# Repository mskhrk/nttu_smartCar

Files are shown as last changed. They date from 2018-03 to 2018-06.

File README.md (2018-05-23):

# nttu_smartCar(Accident detection-home-robot)
居家意外偵測智慧機器人車(Accident detection-home-robot)

歡迎來到國立台東大學資訊工程系的此開源專案

我們志在建立一個自動化的機器裝置，以解決居家意外發生時的問題

我們使用Arduino+linux實現了一個可在家中自動巡邏的機器人車

目前實作完成的項目有機器人車控制(硬體部分)、地圖路徑規劃

目前正在進行中的項目有機器人車控制(軟體部分)、地圖路徑繪製、opencv影像辨識

機器人車控制使用程式語言為 C 

使用 opencv 版本2.4.9 

運作環境 ubuntu-12.04.5 on zedboard zynq-7000

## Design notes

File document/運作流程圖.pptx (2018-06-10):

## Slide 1

main主體

共用全域變數

共用資料結構

智能車主控制程式
(初始狀態設定)
(執行緒建立)

意外檢測
(pthread1)

意外檢測功能
accident_decection.c

accident_decection()

車子相關Io控制
(pthread2)

carMove()

車子相關Io控制功能
carMove.c

影像辨識
(pthread3)

影像辨識功能
image_recognition.c

image_recognition()

無線網路IO&判斷(pthread4)

黃色底色
(待驗證)

treatWifi()

無線網路資料接收
treatWifi.c

紅色底色
(未開始)

橘色底色
(進行中)

綠色底色
(已完成)

## uart_send_command()函數說明

- 在此說明中以uart_send_command() 已usc()表示
- 需與Arduino library(car_all_v5.1.ino)結合使用， usc()用於透過uart傳送指令給Arduino，並且接收Arduino回傳回來的資料，並存於特定檔案(預設data1.txt)之中。
- 目前有uart_send_command()和uart_send_command2()兩個版本，兩者差異在於傳入的參數不同， uart_send_command2() 可自行設定要寫入的檔案名與寫入模式。
- data1.txt為接收資料的暫存檔需搭配使用fixfile()和load_data()才可取出數值使用
- 如果只是要傳送指令而不需接收回傳資料，建議直接使用system()功能。

## fixfile()、 load_data() 函數說明

- fixfile() 是 uart_send_command() 功能的後續處理函式，目的在於將uart_send_command() 所寫入的檔案(data1.txt)進行雜訊處理與資料筆數計算， data1.txt處理後會以data2.txt儲存。
- load_data() 是 fixfile() 功能的後續處理函式，目的在於將data2.txt的資料載入到記憶體中。
- uart_send_command()、 fixfile() 、 load_data() 為相依的程式功能，目的在於將Arduino 送出的特定格式資料進行儲存(disk)與載入(memory)使用。

## 地圖路徑規劃

- 可依照現有地圖(外部環境資訊)，計算出一條可以從起點移動至目標點的路徑。
- 藉由路徑規劃可以實現在有地圖的狀態下，可在空間中進行避障移動。

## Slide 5

實際規劃結果

實際地圖檔案

y

#23 -5003-5002-999-17-0-22-0-0-0-

#22 -5003-5001-999-23-0-21-0-0-0-

#21 -5003-5000-999-22-0-0-20-0-0-

#20 -5002-5000-999-0-21-0-8-0-0-

#19 -5005-5003-999-0-0-0-18-0-0-

#18 -5004-5003-999-0-19-0-17-0-0-

#17 -5003-5003-999-0-18-23-15-0-0-

#16 -5002-5004-999-0-0-15-12-0-0-

#15 -5002-5003-999-16-17-0-11-0-0-

#14 -5001-5006-999-0-0-13-7-0-0-

#13 -5001-5005-999-14-0-12-6-0-0-

#12 -5001-5004-999-13-16-11-5-0-0-

#11 -5001-5003-999-12-15-10-4-0-0-

#10 -5001-5002-999-11-0-9-3-0-0-

#9 -5001-5001-999-10-0-8-2-0-0-

#8 -5001-5000-999-9-20-0-1-0-0-

#7 -5000-5006-999-0-14-6-0-0-0-

#6 -5000-5005-999-7-13-5-0-0-0-

#5 -5000-5004-999-6-12-4-0-0-0-

#4 -5000-5003-999-5-11-3-0-0-0-

#3 -5000-5002-999-4-10-2-0-0-0-

#2 -5000-5001-999-3-9-1-0-0-0-

#1 -5000-5000-999-2-8-0-0-0-0-

7

14

5006

5005

6

13

5004

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
5003

3

10

23

5002

5001

2

9

22

5000

1

5000

8

5001

20

21

X

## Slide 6

實際規劃結果

實際地圖檔案

y

#23 -5003-5002-999-17-0-22-0-0-0-

#22 -5003-5001-999-23-0-21-0-0-0-

#21 -5003-5000-999-22-0-0-20-0-0-

#20 -5002-5000-999-0-21-0-8-0-0-

#19 -5005-5003-999-0-0-0-18-0-0-

#18 -5004-5003-999-0-19-0-17-0-0-

#17 -5003-5003-999-0-18-23-15-0-0-

#16 -5002-5004-999-0-0-15-0-0-0-

#15 -5002-5003-999-16-17-0-0-0-0-

#14 -5001-5006-999-0-0-13-7-0-0-

#13 -5001-5005-999-14-0-0-6-0-0-

#12 -5001-5004-999-0-0-0-0-0-0-

#11 -5001-5003-999-0-0-0-0-0-0-

#10 -5001-5002-999-0-0-9-3-0-0-

#9 -5001-5001-999-10-0-8-2-0-0-

#8 -5001-5000-999-9-20-0-1-0-0-

#7 -5000-5006-999-0-14-6-0-0-0-

#6 -5000-5005-999-7-13-5-0-0-0-

#5 -5000-5004-999-6-0-4-0-0-0-

#4 -5000-5003-999-5-0-3-0-0-0-

#3 -5000-5002-999-4-10-2-0-0-0-

#2 -5000-5001-999-3-9-1-0-0-0-

#1 -5000-5000-999-2-8-0-0-0-0-

7

14

5006

5005

6

13

5004

5

16

4

15

17

18

19

5003

3

10

23

5002

5001

2

9

22

5000

1

5000

8

5001

20

21

X

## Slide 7

實際規劃結果

實際地圖檔案

y

#23 -5003-5002-999-0-0-22-0-0-0-

#22 -5003-5001-999-23-0-21-0-0-0-

#21 -5003-5000-999-22-0-0-20-0-0-

#20 -5002-5000-999-0-21-0-8-0-0-

#19 -5005-5003-999-0-0-0-18-0-0-

#18 -5004-5003-999-0-19-0-0-0-0-

#17 -5003-5003-999-0-0-0-0-0-0-

#16 -5002-5004-999-0-0-15-12-0-0-

#15 -5002-5003-999-16-0-0-0-0-0-

#14 -5001-5006-999-0-0-13-7-0-0-

#13 -5001-5005-999-14-0-12-6-0-0-

#12 -5001-5004-999-13-16-0-5-0-0-

#11 -5001-5003-999-0-0-0-0-0-0-

#10 -5001-5002-999-0-0-9-3-0-0-

#9 -5001-5001-999-10-0-8-2-0-0-

#8 -5001-5000-999-9-20-0-1-0-0-

#7 -5000-5006-999-0-14-6-0-0-0-

#6 -5000-5005-999-7-13-5-0-0-0-

#5 -5000-5004-999-6-12-4-0-0-0-

#4 -5000-5003-999-5-0-3-0-0-0-

#3 -5000-5002-999-4-10-2-0-0-0-

#2 -5000-5001-999-3-9-1-0-0-0-

#1 -5000-5000-999-2-8-0-0-0-0-

7

14

5006

5005

6

13

5004

5

12

16

4

15

18

19

5003

3

10

23

5002

5001

2

9

22

5000

1

5000

8

5001

20

21

X

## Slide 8

實際規劃結果

實際地圖檔案

y

#23 -5003-5002-999-17-0-22-0-0-0-

#22 -5003-5001-999-23-0-21-0-0-0-

#21 -5003-5000-999-22-0-0-20-0-0-

#20 -5002-5000-999-0-21-0-8-0-0-

#19 -5005-5003-999-0-0-0-18-0-0-

#18 -5004-5003-999-0-19-0-17-0-0-

#17 -5003-5003-999-0-18-23-15-0-0-

#16 -5002-5004-999-0-0-15-12-0-0-

#15 -5002-5003-999-16-17-0-11-0-0-

#14 -5001-5006-999-0-0-13-7-0-0-

#13 -5001-5005-999-14-0-12-6-0-0-

#12 -5001-5004-999-13-16-11-5-0-0-

#11 -5001-5003-999-12-15-10-4-0-0-

#10 -5001-5002-999-11-0-0-3-0-0-

#9 -5001-5001-999-0-0-0-0-0-0-

#8 -5001-5000-999-0-20-0-1-0-0-

#7 -5000-5006-999-0-14-6-0-0-0-

#6 -5000-5005-999-7-13-5-0-0-0-

#5 -5000-5004-999-6-12-4-0-0-0-

#4 -5000-5003-999-5-11-3-0-0-0-

#3 -5000-5002-999-4-10-0-0-0-0-

#2 -5000-5001-999--0-0-0-0-0-

#1 -5000-5000-999-0-8-0-0-0-0-

7

14

5006

5005

6

13

5004

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
5003

3

10

23

5002

5001

22

5000

1

5000

8

5001

20

21

X

## 外部環境偵測與地圖建立

- 1.使用超聲波感測器對外部環境進行掃描。
- 2.zedboard發出控制arduino指令:要求回傳超聲波感測器取得數值。
- 3.arduino 接收指令控制步進馬達轉動與超聲波感測器進行資料收集，並回傳zedboard感測器取得的數值。
- 4.zedboard對數值進行處理並依造格式轉換為地圖檔。

## 外部環境偵測與地圖建立

- 藉由超聲波感測器回傳的數值計算牆壁距離並生成地圖

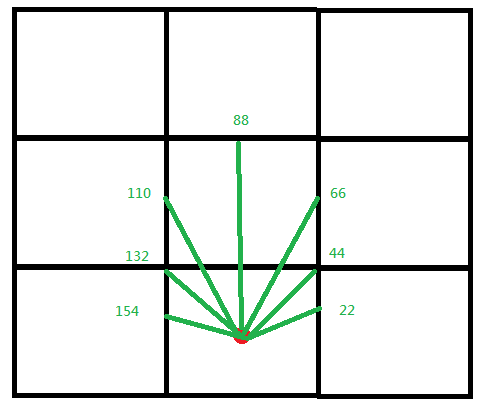
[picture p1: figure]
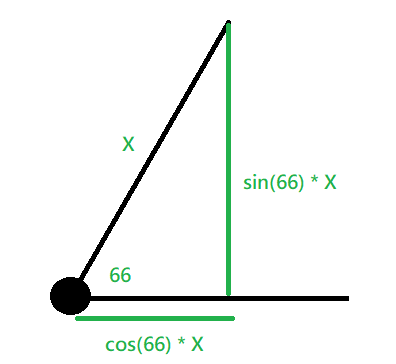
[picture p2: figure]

## 地圖說明

- 用途:用於紀錄車子曾經走過的路徑、移動方式、外部環境樣貌，並結合路徑規劃，使車子可在空間中移動、避障。
- 地圖格式:為了可以方便做資料存取，定義出的一個格式
使用 “#” 作為開頭 “-” 與空白作為分隔，資料以數字表示。
#數字空白-數字-數字-數字-數字-數字-數字-數字-數字-數字-

在此儲存格式下每個位置的資料將有不同的資料含意。

## 地圖說明-資料意義(格式999)

- #序號 -X-Y-格式999-北-東-南-西-分區-預留-(環境資訊)
序號:用於從地圖檔讀取資料的key，儲存序號由1開始向後累加，當同一份地圖檔當中出現重複序號時以最新一筆為讀取目標。
序號0:為定義地圖檔案的標頭與結尾，不儲存資料。
- X Y:分別儲存地圖中x軸y軸的位置。
- 格式:利用數字定義後面儲存的資料格式，使地圖檔可以存放各種不同意義的資料。
  - 格式999說明(記錄環境資訊) :
#序號空格-X-Y-格式999-北-東-南-西-分區-預留
#1 -5000-5000-999-2-8-0-0-0-0-
此例中代表在序號1這一個位置中 向北是序號2，東為序號8，0則代表無路可走，也就是代表0是邊界或障礙。

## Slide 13

主架構

細部流程

多選多
流程1

多選多
流程2

多選一流程1

多選一流程2

紅色底色
(未開始)

橘色底色
(進行中)

黃色底色
(待驗證)

綠色底色
(已完成)

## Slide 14

車子啟動

回傳
地圖可用訊號
將目前位置與方位寫入全域變數

檢測目前
位置與方位

目的讓車子獲得起始資訊
以利後續功能運作

校正(設定)
車子移動參數

控制車子對自身狀態檢測

人工把車子狀態設定

目的讓車子之後的移動可以精準
以利操作

依方位與
地圖ID移動

等待移動指令

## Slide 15

校正(設定)
車子移動參數

自動校正

手動輸入

完成校正

使用linux timer
計時

面向牆壁

結束移動訊號

修改移動參數

紀錄目前距離

開始移動訊號

計時器停止

比較之前距離
計算移動時間

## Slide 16

檢測目前
位置與方位

建立
初始環境

檢測地圖可用性

建立新地圖

判斷失敗

回傳地圖ID
和面相方位

判斷成功

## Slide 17

建立
初始環境

使用modeJ
環境掃描
(開機時北方)

使用initScanXY()
把初始環境
資料存於
car.map

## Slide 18

檢測地圖可用性

檢測目前車子位於地圖中哪一個點

回傳失敗

判斷失敗

回傳目前
位置ID
和面相方位

判斷成功

和現有地圖每1筆比對

相機qrcode 判斷

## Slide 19

建立新地圖

發送探測指令

接收回傳
資料

資料修正與轉換

回傳最終點地圖ID
和面相方位

將資料加上ID
寫入地圖檔

不是最終點

是最終點

依演算法
移動到下一個點

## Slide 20

依演算法
移動到下一個點

判斷地圖還是否
需要繼續製作

距離與XY轉換
車子面向方向
地圖資料更新

一般行走規則

1直走
2最遠45度角
3右優先

移動規則

前4步行走規則

1找四邊緣
2找四邊角

依規則、現有資料判斷
計算下一步命令

送出移動方向和距離

實際移動功能

遇到邊界點

1退回上一個點
2並記錄此點

地圖邊界擴張與結束

計算是否有超出初始邊界的點
如有從此點再做前4步行走直到無邊界外的點

## 程式

car_all_v5.0.ino arduino原始碼
uart_setting.c uart設定函式
sm_car.c 智能車操作函式庫
https://drive.google.com/drive/folders/0BysmffTc7ivUeC1XWUVXUlh1bUE?usp=sharing
-----------------------------------測試code--------------------------------------------
timerInThread.c linux計時器與執行緒測試
timerInThreadJ 定時超音波避障測試

## 預估問題

- 可能問題車子實際移動不符合預期
- 移動角度不准、誤差累積
- 移動時的控制流程(和其他執行緒的相依關係)
- http://viml.nchc.org.tw/blog/paper_info.php?CLASS_ID=1&SUB_ID=1&PAPER_ID=435

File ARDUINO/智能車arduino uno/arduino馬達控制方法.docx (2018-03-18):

頻道A

指令 指令說明 參數 參數說明

1 向前移動 1~9 向前移動1格上限為9格1格定義為60cm

2 向後移動 1~9 向後移動1格上限為9格1格定義為60cm

頻道B

指令 指令說明 參數1 參數1說明 參數2 參數2說明

1 向右移動 1~9 移動時間(秒) 1~3 表示旋轉程度

2 向左移動 1~9 移動時間(秒) 1~3 表示旋轉程度

旋轉程度細節說明 :

程度1 急轉:轉90度後直走此時參數1為轉完後直走時間

程度2 快速側轉此時參數1為側轉全程時間

程度3 側偏此時參數1為側偏全程時間

頻道C

指令 指令說明

0 停止

1 前進

2 後退

頻道D

指令 指令說明 參數 參數說明

1 向右 0~4 轉彎模式

2 向左 0~4 轉彎模式

旋轉模式細節說明 :

0迴旋

1慢速向前

2慢速向後

3快速向前

4快速向後

頻道E

指令 指令說明 參數 參數說明

1 控制速度 1~3 1:高速 2:中速 3:低速

2 控制速度 空1~255 分號 需空一格 1:最低速 255:最高速 (和F5一樣)

3 控制速度 1~2 1:+10單位 2:-10單位 max:255 min:70

4 掃描開關 0~1 0關 1開

頻道F

指令 指令說明 參數 參數說明

1 格子距離 空 1~ 分號 需空一格 走60cm的時間 預設990(ns)

2 誤差距離 空 1~ 分號 需空一格 前進時煞車距離誤差 預設50(ns)

3 誤差距離 空 1~ 分號 需空一格 轉90度的時間 預設900(ns)

4 誤差距離 空 1~ 分號 需空一格 轉180度的時間 預設1900(ns)

5 控制速度 空 1~255分號 需空一格 1:最低速 255:最高速 預設200(ns)

頻道G

指令 指令說明

1 一邊自轉一邊送超音波探測

參數1 參數1說明

空 1~255 旋轉速度(車子轉的速度)

參數2 參數2說明

空 1~ 旋轉時間(車子轉一圈的總時間)

參數3 參數3說明

空 1~ 分號 超音波可測最遠time out(3000時約等於50cm)

頻道H

指令 指令說明

1 可個別控制4個輪子

參數1 參數1說明

空 0~255 or 空1001~1255 rf旋轉速度(車子轉的速度)正轉255 反轉1255 參數2 參數2說明

空 0~255 or 空1001~1255 lb旋轉速度(車子轉的速度)正轉255反轉1255

參數3 參數3說明

空 0~255 or 空1001~1255 rb旋轉速度(車子轉的速度)正轉255 反轉1255

參數4 參數4說明

空 0~255 or 空1001~1255 分號 lf旋轉速度(車子轉的速度)正轉255 反轉1255

頻道I

開始掃描/停止掃描

頻道J

指令 指令說明

1 依照參數回傳旋轉角度超音波讀取值

參數1 參數1說明

空 0~180 起始角度
參數2 參數2說明

空 0~180 結束角度

參數3 參數3說明

空 0~180 每一次轉動的角度

參數4 參數4說明

空 0~20 每一次轉動的超音波發射次數

參數5 參數5說明

空 0~ 分號 每一次轉動的timeout(3000時約等於50cm)

指令 指令說明

2 依照參數回傳單一指定方向超音波讀取值並當回傳值小於20時stopFlag=1

參數1 參數1說明

空 0~180 旋轉角度

參數2 參數2說明

空 0~20 每一次轉動的超音波發射次數

參數3 參數3說明

空 0~ 分號 每一次轉動的timeout(3000時約等於50cm)

頻道K

指令 指令說明 參數 參數說明

1 右旋轉 空1~ 360分號 須為15的倍數

2 左旋轉 空1~ 360分號 須為15的倍數

頻道P

印出目前全域變數

範例

向前走3格:A13

右轉90度後直走2秒:B21

速度改用中速:E12

速度改用自訂義:E2 200;

轉速50 轉4000 ms timeout 3000us G1 50 4000 3000;

印出目前全域變數 P

echo "D10" > /dev/ttyPS1

echo "H1 200 200 200 200;" > /dev/ttyPS1

echo "C1" > /dev/ttyPS1

echo "E2 255;" > /dev/ttyPS1

echo "J1 20 160 5 3;" > /dev/ttyPS1

echo "F6 170;" > /dev/ttyPS1

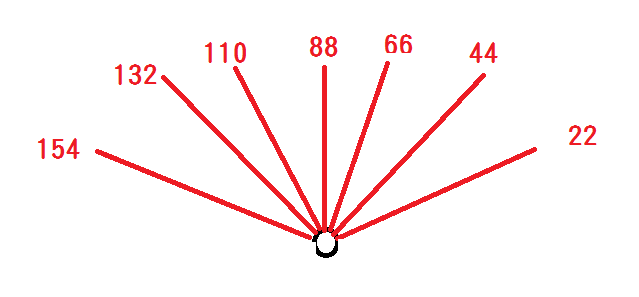
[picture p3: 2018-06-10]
document/picture/seven directional scanning.png

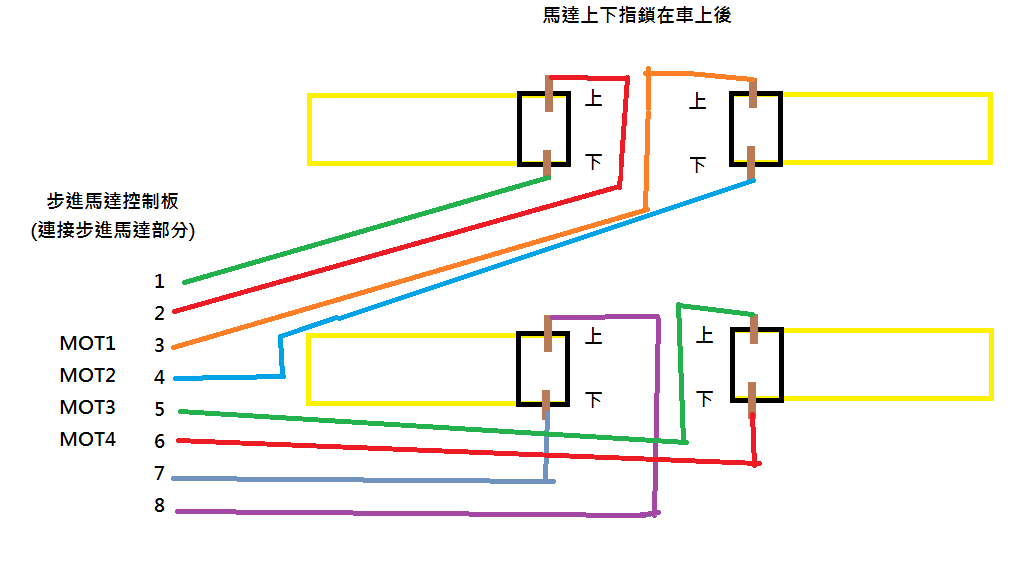
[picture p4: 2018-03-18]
document/智能車電路接線3.png

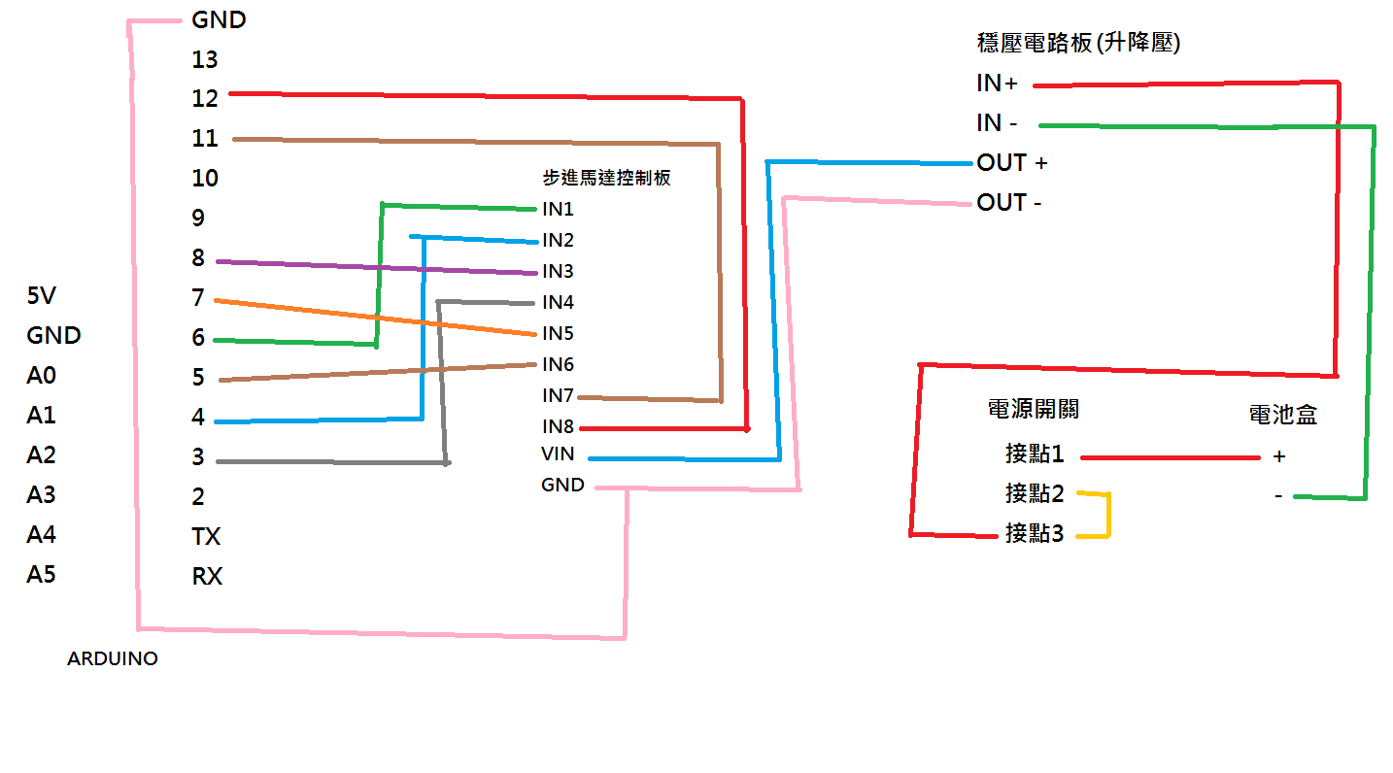
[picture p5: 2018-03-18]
document/智能車電路接線2.png

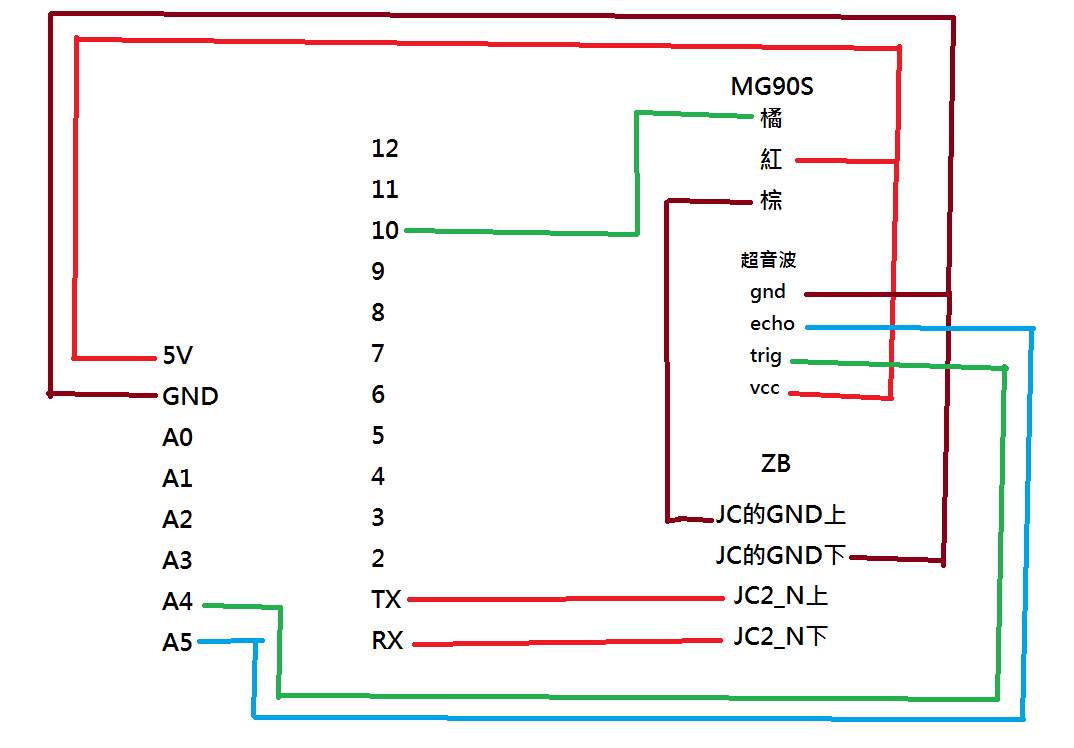
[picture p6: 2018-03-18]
document/智能車電路接線.png

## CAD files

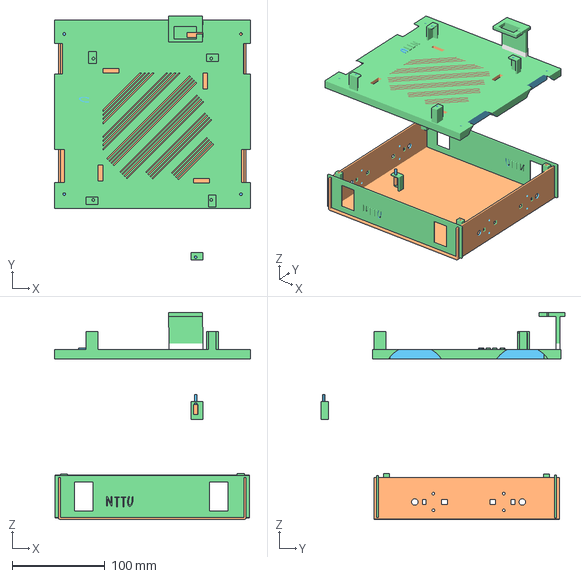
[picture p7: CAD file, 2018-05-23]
3D/car3D.3mf
211.9 x 263.3 x 223.5 mm

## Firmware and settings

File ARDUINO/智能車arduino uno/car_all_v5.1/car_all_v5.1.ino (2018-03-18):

#include <MsTimer2.h>
#include <Servo.h>
/*馬達*/
Servo myservo;

/*移動參數*/
int OneFloorDelay = 890;    //一片木地板行走時間900ns
int FloorDeviation = 50;    //前進時煞車距離誤差
int TurnAround15 =  130;    //旋轉15度所需時間(ns)
int TurnAround90 =  660;    //旋轉90度所需時間(ns)
int TurnAround180 = 1200;   //旋轉180度所需時間(ns)
int TurnAround360 = 2400;   //旋轉360度所需時間(ns)
int CarSpeed = 200;         //移動速度0~255,初始值200

/*控制旗標*/
int stopFlag = 0;           //停止移動旗標
int stopScan = 0;           //停止掃描旗標

/*腳位設定*/
int rb1 = 12;
int rb2 = 11;
int rf1 = 8;
int rf2 = 3;
int lf1 = 7;
int lf2 = 5;
int lb1 = 4;
int lb2 = 6;

/*
int lf1 = 12;
int lf2 = 11;
int lb1 = 8;
int lb2 = 3;
int rb1 = 7;
int rb2 = 5;
int rf1 = 4;
int rf2 = 6;
*/

/*計時器timer參數(5.0版後版本移除timer功能)*/
unsigned long CountTime = 0;
int CountRst = 0;

/*uart外部命令存放字串*/
String s1 = " ";
String s2 = " ";
String s3 = " ";
String s4 = " ";
String s5 = " ";
String s6 = " ";

/*超音波參數*/
int Trig_pin;
int Echo_pin;
long Time_out;
long duration;

//----------------------------

void setup() {

  /*arduino 對應腳位*/
  pinMode(lf1, OUTPUT); //左前
  pinMode(lf2, OUTPUT); //左前
  pinMode(lb1, OUTPUT); //左後
  pinMode(lb2, OUTPUT); //左後
  pinMode(rb1, OUTPUT); //右後
  pinMode(rb2, OUTPUT); //右後
  pinMode(rf1, OUTPUT); //右前
  pinMode(rf2, OUTPUT); //右前
  
  hcrs04_init(18, 19, 3000);        //超音波初始腳位 & timeout設定
  Serial.begin(9600);               //uart通訊速度
  myservo.attach(10, 500, 2400);   //修正伺服脈衝寬度範圍
  myservo.write(90);               //伺服馬達起始角度
  

}


void loop() {

  CommunicationSerial();                  //解析uart送來的指令、並執行
  
  if (stopFlag == 1)  Stop();             //當停止旗標被設定就停止移動
  
  if (stopScan == 1)  Ultrasound_sacn();  //掃描車子超音波範圍內是否有障礙
}

//-超音波---------------------------

/*初始設定函式*/
void hcrs04_init(int TP, int EP, long TO)
{
  pinMode(TP, OUTPUT);
  pinMode(EP, INPUT);
  Trig_pin = TP;
  Echo_pin = EP;
  Time_out = TO;
}

/*超音波掃描函式 回傳值為距離所跑的時間*/
long Timing()
{
  digitalWrite(Trig_pin, LOW);
  delayMicroseconds(2);
  digitalWrite(Trig_pin, HIGH);
  delayMicroseconds(10);
  digitalWrite(Trig_pin, LOW);
  duration = pulseIn(Echo_pin, HIGH, Time_out);
  if ( duration == 0 ) {
    duration = Time_out;
  }
  return duration;
}

/*超音波掃描函式 回傳值為距離(cm)*/
long Ranging()
{
  Timing();
  delayMicroseconds(15);
  return (duration / 29 / 2) ;
}

/*  
 *  超音波掃描函式 測量前方20cm是否有障礙物
 *  有障礙物會設定停止旗標讓車停止(stopFlag)
 *  此函式只有在stopScan被設為1時執行
 *  本函式由loop()來啟動
*/
void Ultrasound_sacn()
{
  int scanAns[6];
  int average = 0;
  int newAverage = 0;
  int count2 = 0;
  int value = 0;
  int i;
    for (i = 0; i < 5; i++) {
      scanAns[i] = Ranging();
      average += scanAns[i];
    }

    average = average / 5;
    for (i = 0; i < 5; i++) {
      if (average - scanAns[i] > 20 || average - scanAns[i] < -20) {}
      else {
        newAverage += scanAns[i];
        count2++;
      }
    }
    if ((newAverage / count2) < 20) {
      stopFlag = 1;
      stopScan = 0;
    }
    average = 0;
    newAverage = 0;
    count2 = 0;
    value = 0;
}

//----------------------------------
/*
 * timer計時
 * 因 timer2 library 會和pwm搶timer所以暫時不使用 
 */
void CountTimeing()
{
  CountTime++;
}

//-----------------------------------

/*uart轉換字串程式*/
String Rx2String()
{
  String s = "";
  char c;
  while (Serial.available() == 0) {}
  while (Serial.available() > 0) {

    c = Serial.read();
    //3層if 有換行空白enter就 break
    if (c == ';')break;
    if (c != '\r') {
      if (c != '\n') {
        if (c != ' ') s += c;
        else {
          break;
        }
      }
      else {
        break;
      }
    }
    else {
      break;
    }

    while (Serial.available() == 0) {} //等下一個字來
  }
  return s;
}

/*uart 指令分析程式*/
void CommunicationSerial()
{
  int value = 0;
  if (Serial.available() > 0) {
    value = Serial.read();
    switch (value) {
      case 10:
        break;

      case 13:
        break;

      case 65:
        Serial.println("in modeA");
        modeA();
        break;

      case 66:
        Serial.println("in modeB");
        modeB();
        break;

      case 67:
      Serial.println("in modeC");
        modeC();
        break;

      case 68:
      Serial.println("in modeD");
        modeD();
        break;

      case 69:
      Serial.println("in modeE");
        modeE();
        break;

      case 70:
      Serial.println("in modeF");
        modeF();
        break;

      case 71:
      Serial.println("in modeG");
        modeG();
        break;

      case 72:
      Serial.println("in modeH");
        modeH();
        break;

      case 73:
      Serial.println("in modeI");
        modeI();
        break;

      case 74:
      //Serial.println("in modeJ");
        modeJ();
        break;

      case 75:
      //Serial.println("in modeK");
        modeK();
        break;

      case 80:
      Serial.println("in modeP");
        modeP();
        break;

      //default:
        //Serial.write(value);
        //Serial.println("  error mode select");
    }
  }
}



void modeA()
{
  int value = 0;
  while (Serial.available() == 0) {}
  value = Serial.read();
  while (Serial.available() == 0) {}
  switch (value) {
    case 49:
      value = Serial.read();
      if (value == 49) {
        go(1);
      }
      else if (value == 50)go(2);
      else if (value == 51)go(3);
      else if (value == 52)go(4);
      else if (value == 53)go(5);
      else if (value == 54)go(6);
      else if (value == 55)go(7);
      else if (value == 56)go(8);
      else if (value == 57)go(9);
      break;

    case 50:
      value = Serial.read();
      if (value == 49)goback(1);
      else if (value == 50)goback(2);
      else if (value == 51)goback(3);
      else if (value == 52)goback(4);
      else if (value == 53)goback(5);
      else if (value == 54)goback(6);
      else if (value == 55)goback(7);
      else if (value == 56)goback(8);
      else if (value == 57)goback(9);
      break;

    default:
      Serial.println("error input in modeA");
  }
}


void modeB()
{
  int value = 0;
  while (Serial.available() == 0) {}
  value = Serial.read();
  while (Serial.available() == 0) {}
  switch (value) {
    case 49:
      value = Serial.read();
      while (Serial.available() == 0) {}
      if (value == 49) {
        value = Serial.read();
        if (value == 49)goRight(1000, 1);
        else if (value == 50)goRight(1000, 2);
        else if (value == 51)goRight(1000, 3);
      }
      else if (value == 50) {
        value = Serial.read();
        if (value == 49)goRight(2000, 1);
        else if (value == 50)goRight(2000, 2);
        else if (value == 51)goRight(2000, 3);
      }
      else if (value == 51) {
        value = Serial.read();
        if (value == 49)goRight(3000, 1);
        else if (value == 50)goRight(3000, 2);
        else if (value == 51)goRight(3000, 3);
      }
      else if (value == 52) {
        value = Serial.read();
        if (value == 49)goRight(4000, 1);
        else if (value == 50)goRight(4000, 2);
        else if (value == 51)goRight(4000, 3);
      }
      else if (value == 53) {
        value = Serial.read();
        if (value == 49)goRight(5000, 1);
        else if (value == 50)goRight(5000, 2);
        else if (value == 51)goRight(5000, 3);
      }
      else if (value == 54) {
        value = Serial.read();
        if (value == 49)goRight(6000, 1);
        else if (value == 50)goRight(6000, 2);
        else if (value == 51)goRight(6000, 3);
      }
      else if (value == 55) {
        value = Serial.read();
        if (value == 49)goRight(7000, 1);
        else if (value == 50)goRight(7000, 2);
        else if (value == 51)goRight(7000, 3);
      }
      else if (value == 56) {
        value = Serial.read();
        if (value == 49)goRight(8000, 1);
        else if (value == 50)goRight(8000, 2);
        else if (value == 51)goRight(8000, 3);
      }
      else if (value == 57) {
        value = Serial.read();
        if (value == 49)goRight(9000, 1);
        else if (value == 50)goRight(9000, 2);
        else if (value == 51)goRight(9000, 3);
      }
      break;

    case 50:
      value = Serial.read();
      while (Serial.available() == 0) {}
      if (value == 49) {
        value = Serial.read();
        if (value == 49)goLeft(1000, 1);
        else if (value == 50)goLeft(1000, 2);
        else if (value == 51)goLeft(1000, 3);
      }
      else if (value == 50) {
        value = Serial.read();
        if (value == 49)goLeft(2000, 1);
        else if (value == 50)goLeft(2000, 2);
        else if (value == 51)goLeft(2000, 3);
      }
      else if (value == 51) {
        value = Serial.read();
        if (value == 49)goLeft(3000, 1);
        else if (value == 50)goLeft(3000, 2);
        else if (value == 51)goLeft(3000, 3);
      }
      else if (value == 52) {
        value = Serial.read();
        if (value == 49)goLeft(4000, 1);
        else if (value == 50)goLeft(4000, 2);
        else if (value == 51)goLeft(4000, 3);
      }
      else if (value == 53) {
        value = Serial.read();
        if (value == 49)goLeft(5000, 1);
        else if (value == 50)goLeft(5000, 2);
        else if (value == 51)goLeft(5000, 3);
      }
      else if (value == 54) {
        value = Serial.read();
        if (value == 49)goLeft(6000, 1);
        else if (value == 50)goLeft(6000, 2);
        else if (value == 51)goLeft(6000, 3);
      }
      else if (value == 55) {
        value = Serial.read();
        if (value == 49)goLeft(7000, 1);
        else if (value == 50)goLeft(7000, 2);
        else if (value == 51)goLeft(7000, 3);
      }
      else if (value == 56) {
        value = Serial.read();
        if (value == 49)goLeft(8000, 1);
        else if (value == 50)goLeft(8000, 2);
        else if (value == 51)goLeft(8000, 3);
      }
      else if (value == 57) {
        value = Serial.read();
        if (value == 49)goLeft(9000, 1);
        else if (value == 50)goLeft(9000, 2);
        else if (value == 51)goLeft(9000, 3);
      }
      break;

    default:
      Serial.println("error input in modeB");
  }
}


void modeC()
{
  int value = 0;
  while (Serial.available() == 0) {}
  value = Serial.read();
  switch (value) {
    case 48:
      Stop();
      break;

    case 49:
      forward();
      break;

    case 50:
      back();
      break;

    default:
      Serial.println("error input in modeC");
  }
}

void modeD()
{
  int value = 0;
  while (Serial.available() == 0) {}
  value = Serial.read();
  while (Serial.available() == 0) {}
  switch (value) {
    case 49:
      value = Serial.read();
      if (value == 48)right(0);
      else if (value == 49)right(1);
      else if (value == 50)right(2);
      else if (value == 51)right(3);
      else if (value == 52)right(4);
      break;

    case 50:
      value = Serial.read();
      if (value == 48)left(0);
      else if (value == 49)left(1);
      else if (value == 50)left(2);
      else if (value == 51)left(3);
      else if (value == 52)left(4);
      break;

    default:
      Serial.println("error input in modeD");
  }
}


void modeE()
{
  s1 = "";
  int value = 0;
  while (Serial.available() == 0) {}
  value = Serial.read();
  while (Serial.available() == 0) {}
  switch (value) {
    case 49:
      value = Serial.read();
      if (value == 49)SetCarSpeed(1);
      else if (value == 50)SetCarSpeed(2);
      else if (value == 51)SetCarSpeed(3);
      break;
    case 50:
      value = Serial.read();
      s1 = Rx2String();
      CarSpeed = atoi(s1.c_str());//c_str()string->char[] | atoi() is char[] to int
      break;
    case 51:
      value = Serial.read();
      if (value == 49) CarSpeed = CarSpeed + 10;
      else if (value == 50)CarSpeed = CarSpeed - 10;
      if (CarSpeed > 255)CarSpeed = 255;
      if (CarSpeed < 70)CarSpeed = 70;
      break;
    case 52:
      value = Serial.read();
      if (value == 48)stopFlag = 0;
      else if (value == 49)stopFlag = 1;
      break;

    default:
      Serial.println("error input in modeE");
  }
}


void modeF()
{
  s1 = "";
  int value = 0;
  while (Serial.available() == 0) {}
  value = Serial.read();
  while (Serial.available() == 0) {}
  switch (value) {
    case 49:
      value = Serial.read();
      s1 = Rx2String();
      OneFloorDelay = atoi(s1.c_str());//c_str()string->char[] | atoi() is char[] to int
      break;
    case 50:
      value = Serial.read();
      s1 = Rx2String();
      FloorDeviation = atoi(s1.c_str());//c_str()string->char[] | atoi() is char[] to int
      break;
    case 51:
      value = Serial.read();
      s1 = Rx2String();
      TurnAround90 = atoi(s1.c_str());//c_str()string->char[] | atoi() is char[] to int
      break;
    case 52:
      value = Serial.read();
      s1 = Rx2String();
      TurnAround180 = atoi(s1.c_str());//c_str()string->char[] | atoi() is char[] to int
      break;
    case 53:
      value = Serial.read();
      s1 = Rx2String();
      CarSpeed = atoi(s1.c_str());//c_str()string->char[] | atoi() is char[] to int
      break;
    case 54:
      value = Serial.read();
      s1 = Rx2String();
      TurnAround15 = atoi(s1.c_str());//c_str()string->char[] | atoi() is char[] to int
      break;
    default:
      Serial.println("error input in modeF");
  }
}

void modeG()
{
  s1 = "";
  s2 = "";
  s3 = "";
  int value = 0;
  int addScan = 1; //MAX415 不可大於4988/12  增加掃描的筆數100
  unsigned int sampleId = 1;
  unsigned long count;
  unsigned long overtime = 0;
  while (Serial.available() == 0) {}
  value = Serial.read();
  while (Serial.available() == 0) {}
  switch (value) {
    case 49:
      value = Serial.read();
      s1 = Rx2String();
      s2 = Rx2String();
      s3 = Rx2String();

      CarSpeed = atoi(s1.c_str());//c_str()string->char[] | atoi() is char[] to int
      TurnAround360 = atoi(s2.c_str());//c_str()string->char[] | atoi() is char[] to int
      Time_out = atol(s3.c_str());//c_str()string->char[] | atol() is char[] to long
      //overtime = TurnAround360/50;
      overtime = TurnAround360 / 100;
      sampleId = 1;
      int i;
      /*數值測試
         Serial.print("overtime ");Serial.println(overtime);
        Serial.print("TurnAround360 ");Serial.println(TurnAround360);
        Serial.print("CarSpeed ");Serial.println(CarSpeed);
        Serial.print("Time_out ");Serial.println(Time_out);*/
      Serial.println("#0 -star-");//輸出開始訊號
      right(0);//開始迴旋
      for (count = 0; count <= overtime; count++) {
        for (i = 0; i < addScan; i++) {
          Serial.print("#");
          Serial.print(sampleId);
          sampleId++;
          Serial.print(" -");
          Serial.print(Ranging());
          Serial.println("-");
        }
        delayMicroseconds(4988 - (12 * addScan));
        delay(95);//每一次循環總和12+988+99000=100000us=100ms
      }

      Stop();
      Serial.println("#0 -over-;");//輸出結束訊號
      break;

    default:
      Serial.println("error input in modeG");
  }
}


void modeH()
{
  s1 = "";
  s2 = "";
  s3 = "";
  s4 = "";
  int rfSpeed, rbSpeed, lbSpeed, lfSpeed;
  int value = 0;
  while (Serial.available() == 0) {}
  value = Serial.read();
  while (Serial.available() == 0) {}
  switch (value) {
    case 49:
      value = Serial.read();
      s1 = Rx2String();
      s2 = Rx2String();
      s3 = Rx2String();
      s4 = Rx2String();

      rfSpeed = atoi(s1.c_str());//c_str()string->char[] | atoi() is char[] to int
      rbSpeed = atoi(s2.c_str());//c_str()string->char[] | atoi() is char[] to int
      lbSpeed = atoi(s3.c_str());//c_str()string->char[] | atol() is char[] to int
      lfSpeed = atoi(s4.c_str());//c_str()string->char[] | atol() is char[] to int

      if (rfSpeed <= 255)
      {
        analogWrite(rf2, rfSpeed);//rf
        digitalWrite(rf1, LOW);
      }
      else {
        analogWrite(rf2, 255 - (rfSpeed - 1000));
        digitalWrite(rf1, HIGH);
      }

      if (rbSpeed <= 255)
      {
        analogWrite(rb2, 255 - rbSpeed); //11
        digitalWrite(rb1, HIGH);
      }
      else {
        analogWrite(rb2, rbSpeed - 1000); //11
        digitalWrite(rb1, LOW);
      }

      if (lbSpeed <= 255)
      {
        analogWrite(lb2, 255 - lbSpeed); //11
        digitalWrite(lb1, HIGH);
      }
      else {

        analogWrite(lb2, lbSpeed - 1000); //11
        digitalWrite(lb1, LOW);
      }

      if (lfSpeed <= 255)
      {
        analogWrite(lf2, lfSpeed);//11
        digitalWrite(lf1, LOW);
      }
      else {
        analogWrite(lf2, 255 - (lfSpeed - 1000)); //11
        digitalWrite(lf1, HIGH);
      }

    default:
      Serial.println("error input in modeH");
  }
}

void modeI()
{
  
  /*原始modeI timer程式
   * if(CountRst==1){CountRst=0;CountTime=0;}
    if(CountTime!=0)
    {MsTimer2::stop( );CountRst=1;}
    else
    { MsTimer2::set(10,CountTimeing); // INTERVAL 1ms 0.001 秒
    MsTimer2::start( );}*/
  
  /*因timer 不使用 modeI 改為設定stopScan 掃描旗標
    當呼叫後就改變旗標狀態
  */
  if (stopScan == 1) {
    stopScan = 0;
  }
  else {
    stopScan = 1;
  }
}


void modeJ()
{
  s1 = "";
  s2 = "";
  s3 = "";
  s4 = "";
  s5 = "";
  int scanAns[20];
  int average = 0;
  int newAverage = 0;
  int count2 = 0;
  int starAngle, overAngle, oneAngle, scanTime;
  int value = 0;
  int i;
  unsigned int sampleId = 1;
  unsigned long count;
  while (Serial.available() == 0) {}
  value = Serial.read();
  while (Serial.available() == 0) {}
  switch (value) {
    case 49:
      value = Serial.read();
      s1 = Rx2String();//起始角度
      s2 = Rx2String();//結束角度
      s3 = Rx2String();//每一次轉動的角度
      s4 = Rx2String();//每一次轉動的超音波發射次數
      s5 = Rx2String();//超音波timeout

      starAngle = atoi(s1.c_str());//c_str()string->char[] | atoi() is char[] to int
      overAngle = atoi(s2.c_str());//c_str()string->char[] | atoi() is char[] to int
      oneAngle = atoi(s3.c_str());//c_str()string->char[] | atoi() is char[] to int
      scanTime = atoi(s4.c_str());//c_str()string->char[] | atoi() is char[] to int
      Time_out = atol(s5.c_str());//c_str()string->char[] | atol() is char[] to long

      if (starAngle > 180 || starAngle < 0) {
        Serial.println("starAngle error");
        break;
      }
      if (overAngle > 180 || overAngle < 0) {
        Serial.println("overAngle error");
        break;
      }
      if (oneAngle > 180 || oneAngle < 0) {
        Serial.println("oneAngle error");
        break;
      }
      if (scanTime > 20 || scanTime < 0) {
        Serial.println("scanTime error");
        break;
      }
      if (Time_out < 0) {
        Serial.println("Time_out error");
        break;
      }

      Serial.println("#0 -star-");//輸出開始訊號
      for (count = starAngle; count <= overAngle; count += oneAngle) {
        myservo.write(count);
        delay(300);//10ms電源共用間隔延遲
        for (i = 0; i < scanTime; i++) {
          Serial.print("#");
          Serial.print(sampleId);
          sampleId++;
          Serial.print(" -");
          Serial.print(Ranging());
          Serial.println("-");
        }
        delay(300);//10ms電源共用間隔延遲
      }
      myservo.write(90); //轉回中間
      Serial.println("#0 -over-;");//輸出結束訊號
      break;

    case 50:
      value = Serial.read();
      s1 = Rx2String();//目標角度
      s2 = Rx2String();//每一次轉動的超音波發射次數
      s3 = Rx2String();//超音波timeout

      starAngle = atoi(s1.c_str());//c_str()string->char[] | atoi() is char[] to int
      scanTime = atoi(s2.c_str());//c_str()string->char[] | atoi() is char[] to int
      Time_out = atol(s3.c_str());//c_str()string->char[] | atol() is char[] to long

      if (starAngle > 180 || starAngle < 0) {
        Serial.println("starAngle error");
        break;
      }
      if (scanTime > 20 || scanTime < 0) {
        Serial.println("scanTime error");
        break;
      }
      if (Time_out < 0) {
        Serial.println("Time_out error");
        break;
      }

      Serial.println("#0 -star-");//輸出開始訊號

      myservo.write(starAngle);
      delay(100);//10ms電源共用間隔延遲
      for (i = 0; i < scanTime; i++) {
        scanAns[i] = Ranging();
        average += scanAns[i];
      }
      average = average / scanTime;
      for (i = 0; i < scanTime; i++) {
        if (average - scanAns[i] > 30 || average - scanAns[i] < -30) {}
        else
        {
          newAverage += scanAns[i];
          count2++;
        }
      }
      if ((newAverage / count2) < 20)stopFlag = 1;
      Serial.print("#"); Serial.print(sampleId); Serial.print(" -"); Serial.print((newAverage / count2)); Serial.println("-");
      average = 0;
      newAverage = 0;
      count2 = 0;
      delay(100);//10ms電源共用間隔延遲
      myservo.write(90); //轉回中間
      Serial.println("#0 -over-;");//輸出結束訊號
      break;

    default:
      //Serial.println("error input in modeJ");
      //Serial.write(value);
      {}
  }
}

void modeK()
{
  s1 = "";
  int value = 0;
  int rotationAngle=0;//外部輸入旋轉角度
  while (Serial.available() == 0) {}
  value = Serial.read();
  while (Serial.available() == 0) {}
  switch (value) {
    case 49:
      value = Serial.read();
      s1 = Rx2String();
      rotationAngle = atoi(s1.c_str());//c_str()string->char[] | atoi() is char[] to int
      if(rotationAngle>360 ||rotationAngle<0){Serial.println("rotationAngle error");}
      rotationAngle=rotationAngle/15;
      if(rotationAngle==6){turnAround(1); }
      if(rotationAngle==12){turnAround(2); }
      if(rotationAngle!=6&&rotationAngle!=12){
      for(;rotationAngle!=0;rotationAngle--)
      {turnAround(5); }
      }
      break;
    case 50:
      value = Serial.read();
      s1 = Rx2String();
      rotationAngle = atoi(s1.c_str());//c_str()string->char[] | atoi() is char[] to int
      if(rotationAngle>360 ||rotationAngle<0){Serial.println("rotationAngle error");}
      rotationAngle=rotationAngle/15;
      if(rotationAngle==6){turnAround(3); }
      if(rotationAngle==12){turnAround(4); }
      if(rotationAngle!=6&&rotationAngle!=12){
      for(;rotationAngle!=0;rotationAngle--)
      {turnAround(6); }
      }
      break;
      
    default:
      Serial.println("error input in modeK");
  }
}
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

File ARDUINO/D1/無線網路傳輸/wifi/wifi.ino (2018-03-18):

#include <ESP8266WiFi.h>
#include <WiFiClient.h>
#include <WiFiServer.h>

//以下為必要全域變數
#define PORT 12345
WiFiClient client;
IPAddress ip(192,168,0,123);
IPAddress gateway(192,168,0,1);
IPAddress subnet(255,255,255,0);
WiFiServer server(PORT);
String dataClient;
String dataServer;
const char *ssid="AP_501";
const char *pass="noxim_lab";
const int gasPin = A0;
String data="";
void setup() {
wifiInit();//請先呼叫這個程式一次
}

void loop() {
data=data+analogRead(gasPin);
  
sendMessage("MQ4"+data);//要傳送的字串直接輸入在此
data="";
sendMessage("MQ4");//要傳送的字串直接輸入在此

}

void wifiInit()
{
  Serial.begin(115200);
  Serial.println("");
  Serial.print("Server Port : ");
  Serial.println(PORT);
  //pinMode(BUILTIN_LED,OUTPUT);// output LED
  //pinMode(12,OUTPUT);//output buzzer
  WiFi.config(ip, gateway, subnet);
  WiFi.begin(ssid,pass);
  while(WiFi.status()!=WL_CONNECTED){
    Serial.print(".");
    delay(500);}
  Serial.println("");
  Serial.print("link to : ");
  Serial.println(ssid);
  Serial.print("Server static IP : ");
  Serial.println(WiFi.localIP());
  delay(200);
  server.begin();//當server被連 server 啟動
}
void sendMessage(String message)
{
   while(!client.connected()){
  client=server.available();
  }

 while(client.connected()){
  //Serial.println(" data from server to client : ");
  //dataServer = "#0 -true-;"; // 跌倒為true
  client.print(message);//server send data to client
  Serial.print("Send message:");
  Serial.println(message);
  delay(1000); //every 1 second
  client.stop();
  dataClient="";
 }
}

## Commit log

2018-03-05 初始上傳
2018-03-18 上傳本地檔案
    arduino 部分
2018-03-19 0319
    刪除 arduino環境建置教學影片
    新增 檔案說明
2018-03-25 語言整合測試
    新增 opencv外部連結函式庫問題.txt
    修改 開發記事本.txt
2018-03-29 20180329
    修正 ‘treatWifi’ warning
2018-04-01 20180401
    main流程圖更新
2018-04-01 20180401-2
    carMove.c 註解修改
    accident_decection.c 註解新增
2018-04-02 20180402
    流程圖地圖說明
    sm_car.tem.c改寫地圖運作
2018-04-08 20180408
    修正 sleep()&printf()
    修正 為紀錄起始位置原因
2018-04-20 20180420
    add test_findPath
    fix carMove
    fix sm_car.c
    [sm_car.c]
2018-04-20 20180420-2
    運作流程圖 更新
2018-04-25 20180426
    第2備援修正中
2018-04-26 20180426-2
    路徑規劃完成
2018-05-23 20180523
    3D列印車殼
    [car3D.3mf]
2018-05-28 20180528
    修改test資料夾為範例資料夾
    修正sm_car.c 中 不必要功能移至unUseFunction.c
    [sm_car.c]
2018-06-03 20180603
    文件更新
    開始 檢測目前位置與方位功能建置
2018-06-15 20180615
    地圖轉換ing
2018-08-09 20180809
    google 網頁搜尋測試
